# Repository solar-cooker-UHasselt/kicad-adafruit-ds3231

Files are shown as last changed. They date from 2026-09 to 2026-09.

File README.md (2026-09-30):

# kicad-adafruit-ds3231





A breakout board for the DS3231, a precision real-time clock with a built-in
temperature-compensated crystal and a CR1220 coin cell that keeps the time without
power. It is a KiCad 10 port of
[Adafruit's DS3231 breakout](https://github.com/adafruit/Adafruit-DS3231-Precision-RTC-Breakout-PCB),
originally drawn in Eagle.

In the [solar cooker](https://github.com/solar-cooker-UHasselt) testing station, the
firmware ([arduino-code](https://github.com/solar-cooker-UHasselt/arduino-code)) reads
the date and time from it over I²C to stamp every measurement and to name the CSV
files on the microSD card.

3D render of the board, top side (https://solar-cooker-uhasselt.github.io/kicad-adafruit-ds3231/)

- [Board page](https://solar-cooker-uhasselt.github.io/kicad-adafruit-ds3231/): 3D
  renders, drawings, schematic and board PDF, interactive BOM and the BOM CSV for
  Eurocircuits, rebuilt by CI on every push to `main`
- [PCB source](https://github.com/adafruit/Adafruit-DS3231-Precision-RTC-Breakout-PCB):
  Adafruit's Eagle files
- [Adafruit guide](https://learn.adafruit.com/adafruit-ds3231-precision-rtc-breakout):
  pinout, wiring and Arduino examples

## Installation

### Requirements

- [KiCad 10](https://www.kicad.org/download/), to open and edit the board
- [git](https://git-scm.com), to clone the repo with its library
- Optional, for the checks: [just](https://just.systems), and for `just ci`
  [act](https://github.com/nektos/act) with Docker

### Clone

Own symbols, footprints and 3D models come from
[kicad-common](https://github.com/solar-cooker-UHasselt/kicad-common), a git submodule
at `kicad-common/`. Clone with it:

```bash
git clone --recurse-submodules https://github.com/solar-cooker-UHasselt/kicad-adafruit-ds3231.git
```

Or, in a clone made without it:

```bash
just setup
```

## Usage

Open `DS3231.kicad_pro` in KiCad 10. The schematic and board open from there.

ERC and DRC, reports in `tmp/`:

```bash
just check
```

DRC also checks the board maker's limits: `DS3231.kicad_dru` holds the Eurocircuits
PCB proto rules (class 6C), a copy of the file in `kicad-common/design-rules/`. After
updating `kicad-common`, refresh the copy (`just check` fails until then):

```bash
just rules
```

Schematic and board PDF in `outputs/` (CI also makes them, as the `outputs` artifact):

```bash
just pdf
```

The same, then open both in the default PDF viewer (Linux and macOS):

```bash
just open
```

The KiBot CI workflow, locally:

```bash
just ci
```

All recipes:

```bash
just --list
```

## Contributing

- Every push and pull request runs ERC and DRC in CI, through the shared workflows in
  [kicad-ci](https://github.com/solar-cooker-UHasselt/kicad-ci). A push to `main` also
  rebuilds the board page.
- Commits follow Conventional Commits, with one change per commit. Types, scopes and the
  ERC/DRC check are in
  [.agents/commit_conventions.md](.agents/commit_conventions.md).
- This is the reference repo for the other board repos: a change to the board setup,
  CI or docs is made and tested here first.

## Authors and acknowledgment

The board is Adafruit's design, by Limor Fried/Ladyada for Adafruit Industries
([PCB source](https://github.com/adafruit/Adafruit-DS3231-Precision-RTC-Breakout-PCB)).
The KiCad 10 port is by Lowie Van Vyve for the UHasselt solar cooker project.

Adafruit invests time and resources providing this open source design. Please support
Adafruit and open-source hardware by purchasing products from
[Adafruit](https://www.adafruit.com).

<details>
<summary>Adafruit's original README, included as its license asks</summary>

> **Adafruit DS3231 Precision RTC Breakout PCB**
>
> [Click here to purchase one from the Adafruit shop](http://www.adafruit.com/products/5188)
>
> [Click here to purchase one from the Adafruit shop](http://www.adafruit.com/products/3013)
>
> The datasheet for the DS3231 explains that this part is an "Extremely Accurate
> I²C-Integrated RTC/TCXO/Crystal". And, hey, it does exactly what it says on the tin!
> This Real Time Clock (RTC) is the most precise you can get in a small, low power
> package.
>
> Most RTCs use an external 32kHz timing crystal that is used to keep time with low
> current draw. And that's all well and good, but those crystals have slight drift,
> particularly when the temperature changes (the temperature changes the oscillation
> frequency very very very slightly but it does add up!) This RTC is in a beefy package
> because the crystal is inside the chip! And right next to the integrated crystal is a
> temperature sensor. That sensor compensates for the frequency changes by adding or
> removing clock ticks so that the timekeeping stays on schedule.
>
> This is the finest RTC you can get, and now we have it in a compact,
> breadboard-friendly breakout. With a coin cell plugged into the back, you can get
> years of precision timekeeping, even when main power is lost. Great for datalogging
> and clocks, or anything where you need to really know the time.
>
> PCB files for the Adafruit DS3231 Precision RTC Breakout. The format is EagleCAD
> schematic and board layout
>
> - https://www.adafruit.com/products/3013
>
> **License**
>
> Adafruit invests time and resources providing this open source design, please support
> Adafruit and open-source hardware by purchasing products from
> [Adafruit](https://www.adafruit.com)!
>
> All text above must be included in any redistribution
>
> Designed by Limor Fried/Ladyada for Adafruit Industries. Creative Commons
> Attribution/Share-Alike, all text above must be included in any redistribution. See
> license.txt for additional information.

</details>

## License

[CC BY-SA 4.0](LICENSE). Adafruit's original design is licensed CC BY-SA 3.0, which
allows adaptations like this port under a later version with the same terms.

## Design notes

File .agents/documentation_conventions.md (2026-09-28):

# Documentation conventions

This repo's documentation rules. The shared conventions are the `check-docs` skill,
which reads this file first and follows it where the two differ.

## Doc map

Each document and the one type it is:

| File | Type |
| --- | --- |
| `README.md` | how-to |
| `AGENTS.md` | reference |
| `.agents/commit_conventions.md` | reference |
| `.agents/documentation_conventions.md` | reference |

`kicad-common/` is a submodule with its own docs, not checked here.

## Where things go

- **`docs/`**: none yet.
- **`.agents/`**: `commit_conventions.md` (types, scopes, the ERC/DRC check per
  commit), `documentation_conventions.md` (this file).

## Exceptions

- **KiCad project name.** The project and its files are named after the board's main
  part, written as the part is printed: `DS3231.kicad_pro`, `.kicad_sch`, `.kicad_pcb`.
  KiCad names every output after the project (the PDFs, the renders on the board page),
  so a rename would change the board page's file URLs.
- **KiCad's own names.** `sym-lib-table` and `fp-lib-table` are the names KiCad looks
  for.

## Check

Every relative link in the repo's own Markdown resolves: the fallback link check in the
`check-docs` skill.

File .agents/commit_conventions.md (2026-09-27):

# Commit conventions

This repo's commit rules. The shared procedure is the `propose-commit` skill, which
reads this file first and follows it where the two differ.

## Check

Every commit leaves ERC and DRC no worse than the commit before it:

```bash
just check
```

It runs ERC and DRC with `kicad-cli` and writes the reports to `tmp/`. For a change to
the CI workflow, also run `just ci`.

Compare the violation counts with the previous commit. A commit that fixes violations
says which ones in its body.

## Types

Choose by the change's *nature*, not by copying past messages.

| Type | When to use |
| --- | --- |
| `feat` | A new part, circuit or board feature |
| `fix` | Corrects a design error: ERC/DRC violation, footprint, value |
| `refactor` | Placement or routing changed, same netlist |
| `style` | Silkscreen or schematic layout only, no electrical change |
| `build` | KiCad file format or library format upgrades |
| `ci` | `.github/workflows/` and `config.kibot.yml` |
| `docs` | README and other documentation |
| `chore` | `.gitignore`, agent files, other maintenance |

## Scope

Optional. In use: `sch` (schematic), `pcb` (board), `bom` (BOM fields), `lib`
(library tables and the `kicad-common/` submodule). Leave the scope out when a commit spans several.

## Rules

- Breaking changes: a KiCad file format upgrade is one-way, older KiCad versions can
  no longer open the files. Mark it with `!` and a `BREAKING CHANGE:` footer naming the
  KiCad version now required.
- One kind of change per commit. A format upgrade contains only what KiCad rewrote on
  save: no zone refill, no library updates, no fixes.
- Never commit `*.kicad_prl`, lock files (`~*`) or generated outputs. `.gitignore`
  covers them.

## Well-formed examples

```
build!: upgrade schematic and board to KiCad 10
build(lib): upgrade footprint library to KiCad 10 format
ci: pin KiBot to the KiCad 10 image
fix(sch): add PWR_FLAG on VCC
chore: add commit conventions and ignore tmp/
```

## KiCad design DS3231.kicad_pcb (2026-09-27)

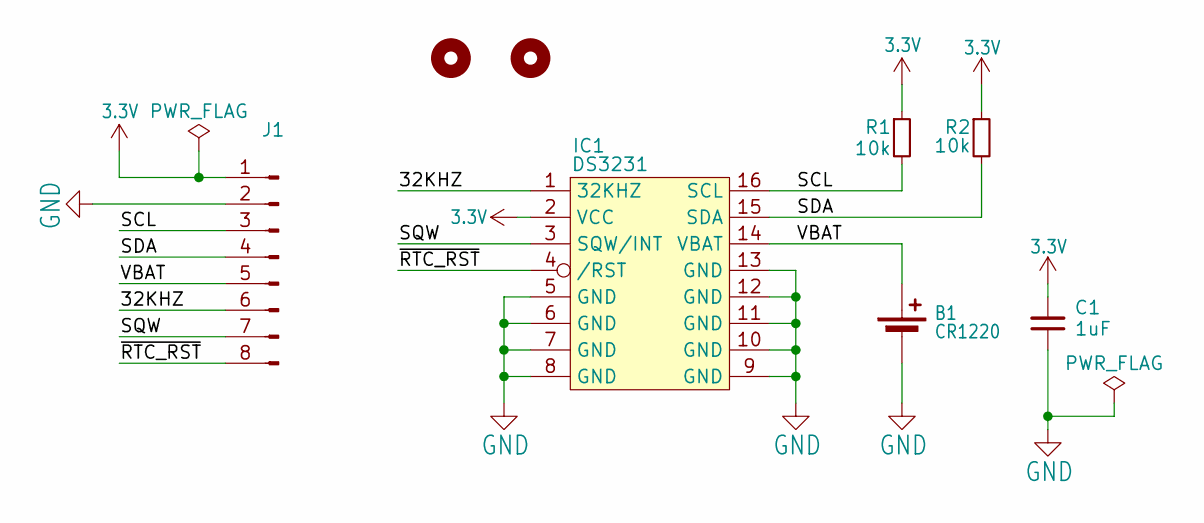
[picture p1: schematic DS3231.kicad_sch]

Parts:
B1: CR1220; BatteryHolder_Keystone_3000_1x12mm; MPN 3000
C1: 1uF; C_0805_2012Metric; MPN /
IC1: DS3231; SOIC-16W_7.5x10.3mm_P1.27mm; MPN DS3231M+TRL
J1: Conn_01x08_Pin; PinHeader_1x08_P2.54mm_Vertical; MPN TSW-108-23-G-S
R1, R2: 10k; R_0805_2012Metric; MPN /
U$1, U$2: MOUNTINGHOLE2.5; MountingHole_2.5mm

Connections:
3.3V: C1.2, IC1.2 (VCC), J1.1, R1.1, R2.1
/32KHZ: IC1.1 (32KHZ), J1.6
/SCL: IC1.16 (SCL), J1.3, R1.2
/SDA: IC1.15 (SDA), J1.4, R2.2
/SQW: IC1.3 (SQW/INT), J1.7
/VBAT: B1.1 (+), IC1.14 (VBAT), J1.5
/~RTC_RST: IC1.4 (/RST), J1.8
GND: B1.2 (-), C1.1, IC1.5 (GND), IC1.6 (GND), IC1.7 (GND), IC1.8 (GND), IC1.9 (GND), IC1.10 (GND), IC1.11 (GND), IC1.12 (GND), IC1.13 (GND), J1.2

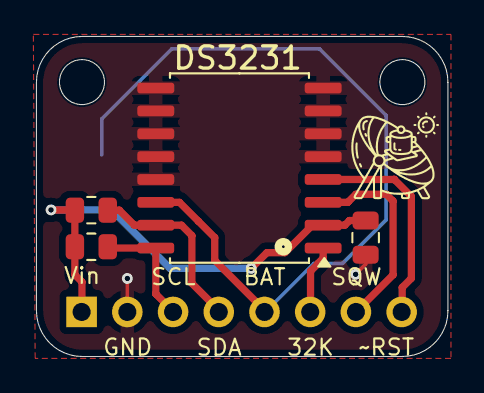
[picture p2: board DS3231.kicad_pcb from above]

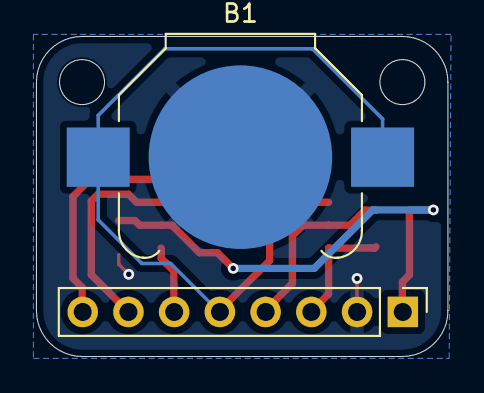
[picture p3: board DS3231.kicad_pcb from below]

Board: 2 copper layers, 22.9 x 17.8 mm, 8 parts (2 on the bottom side), 8 nets.

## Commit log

2024-03-05 blank KiCad project
    [DS3231.kicad_pcb, DS3231.kicad_sch]
2024-03-05 Eagle import
    [DS3231.kicad_pcb, DS3231.kicad_sch]
2024-03-06 added drawing sheet
    [DS3231.kicad_pcb, DS3231.kicad_sch]
2024-03-06 fully migrated to KiCad
    [DS3231.kicad_pcb, DS3231.kicad_sch]
2024-03-06 added info to generate BOM file
    [DS3231.kicad_sch]
2024-03-07 fixed incorrect item in BOM
    [DS3231.kicad_pcb, DS3231.kicad_sch]
2024-04-01 updated routing + symbol update
    [DS3231.kicad_pcb, DS3231.kicad_sch]
2024-04-01 silkscreen + routing update
    [DS3231.kicad_pcb]
2024-04-01 added ground plane front and bottom
    [DS3231.kicad_pcb]
2024-04-01 production ready
    [DS3231.kicad_pcb]
2024-04-03 removed unused copper layers
    [DS3231.kicad_pcb]
2024-04-03 changed copper finish + solder mask and silkscreen color update
    [DS3231.kicad_pcb]
2024-05-02 changed pin header orientation
    [DS3231.kicad_pcb]
2024-05-21 CR1220 footprint update
    [DS3231.kicad_pcb, DS3231.kicad_sch]
2024-06-10 BOM presets update
    [DS3231.kicad_sch]
2026-09-26 chore: ignore KiCad local history
2026-09-26 build!: upgrade schematic and board to KiCad 10
    [DS3231.kicad_pcb, DS3231.kicad_sch]
2026-09-26 build(lib): upgrade libraries to KiCad 10 format
2026-09-26 ci: run KiBot in a pinned KiCad 10 image
2026-09-26 build(pcb): refill zones with KiCad 10
    [DS3231.kicad_pcb]
2026-09-26 fix(sch): add PWR_FLAG on 3.3V and GND
    [DS3231.kicad_sch]
2026-09-26 fix(sch): exclude mounting holes from position files
    [DS3231.kicad_sch]
2026-09-26 fix(pcb): sync SPN of IC1 from the schematic
    [DS3231.kicad_pcb]
2026-09-26 docs: add CI and KiCad version badges
2026-09-26 ci: call the shared KiBot workflow from kicad-ci
2026-09-26 chore: resave drawing sheet in KiCad 10
2026-09-26 docs: fill in the title block
    [DS3231.kicad_pcb, DS3231.kicad_sch]
2026-09-26 style: tighten the drawing sheet title block
2026-09-26 chore: add just recipes for schematic and board PDF
2026-09-26 ci: use the kicad-ci default KiBot config
2026-09-27 ci: publish the board page to GitHub Pages
2026-09-27 docs: link the board page
2026-09-27 ci: name the kicad-ci jobs
2026-09-27 fix: use the Keystone 3000 battery holder
    [DS3231.kicad_pcb, DS3231.kicad_sch]
2026-09-27 fix: ground DS3231 pins 5 to 12
    The datasheet says these N.C. pins must be connected to ground, they
    were left open. Rename them GND in the symbol, wire them to GND and
    connect the pads in the layout.
    [DS3231.kicad_pcb, DS3231.kicad_sch]
2026-09-27 build(lib): use the kicad-common library
    Own parts now come from the shared kicad-common submodule instead of
    copies in external/. IC1 and the logo point to solar_cooker, with the
    same netlist and ERC/DRC results.
    [DS3231.kicad_pcb, DS3231.kicad_sch]
2026-09-27 fix(bom): add the IC1 datasheet link
    [DS3231.kicad_pcb, DS3231.kicad_sch]
2026-09-27 docs: explain cloning with kicad-common
2026-09-27 chore: point the lib scope at kicad-common
2026-09-28 docs: link the KiCad 10 badge to the download page
2026-09-28 docs: describe the board and reshape the README
2026-09-28 chore(lib): update kicad-common for the design rules
2026-09-28 feat: check DRC against Eurocircuits PCB proto
2026-09-30 docs: name the BOMs on the board page
2026-09-30 chore: let Renovate update kicad-common
2026-10-24 docs: describe the pull request flow
2026-10-25 chore: record DS3231.kicad_dru as a project name exception
2026-10-25 docs: link the org CONTRIBUTING.md for the pull request flow
2026-11-09 chore(lib): update kicad-common digest to 368d51c (#4)
2026-11-10 chore: point agents at the board notes
